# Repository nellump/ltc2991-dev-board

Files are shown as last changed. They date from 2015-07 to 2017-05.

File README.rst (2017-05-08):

LTC2991 Development Board
=========================

A simple printed circuit board that makes it easy to plug the
surface-mount (MSOP-16) `LTC2991`_ into a common breadboard.

.. _LTC2991: http://www.linear.com/product/LTC2991

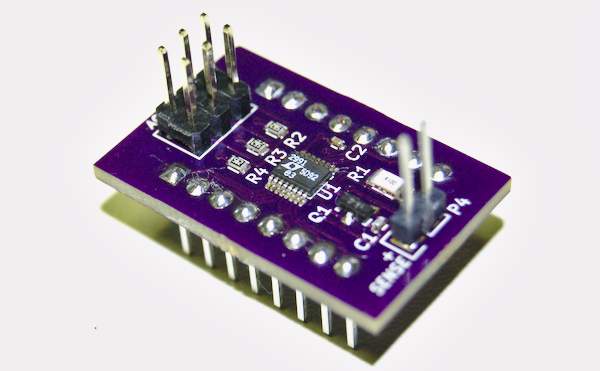
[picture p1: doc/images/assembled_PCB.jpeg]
Photo of LTC2991 breakout board.


   A fully-assembled LTC2991 breakout board, ready for service.

Features
--------

* A pair of pin headers for each of the LTC2991's address lines.
  Jumpering the pins on any given address line connects that line to
  ground.
* Pads suitable for a current-sensing shunt resistor (1206 SMD),
  connected across the V1 and V2 terminals of the LTC2991, and pads
  for a 1x2 pin header to connect said shunt to the outside world.
* Pads suitable for a temperature-sensing, diode-connected NPN BJT
  (SOT-23 SMD), connected across the V3 and V4 terminals of the
  LTC2991, and a filter capactitor for said transistor.

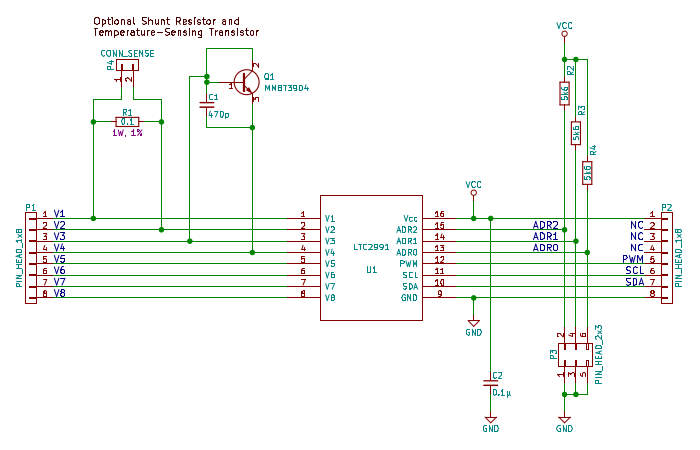
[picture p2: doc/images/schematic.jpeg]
Carrier board schematic.


   Carrier board schematic.  A PDF copy is in the build/ subdirectory.

Caveats
-------

There seems to be no such thing as a breadboard standard.  This PCB
was designed to work with an `R.S.R.-branded breadboard`_.  It
features a 0.100" pin pitch, and an approx. 0.300" gap down the middle
of the board.

.. _R.S.R.-branded breadboard: http://rsrelectronics.com/breadboards.html

Changelog
---------

Rev. A
~~~~~~
Initial design.

Rev. B
~~~~~~
* Added two-pin header for measurement of external current source
  via on-board shunt resistor (both optional).
* Added filter capacitor for IC power.
* Added filter capacitor for temperature-sensing transistor (both
  optional).
* Placed noise-shielding traces around temperature-sensing
  transistor.

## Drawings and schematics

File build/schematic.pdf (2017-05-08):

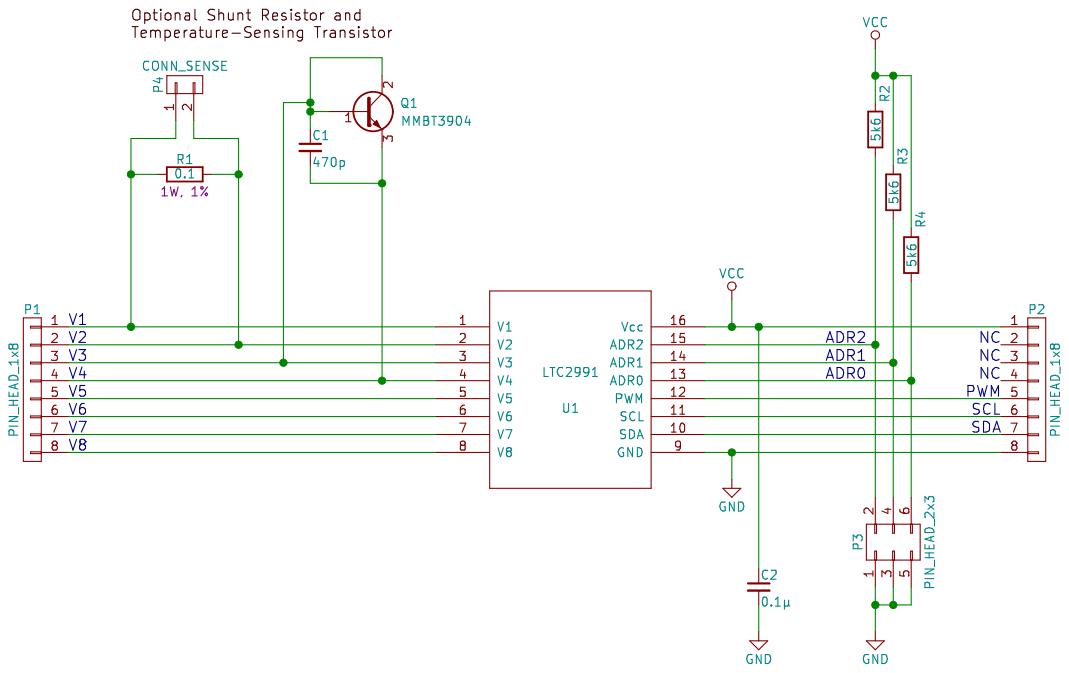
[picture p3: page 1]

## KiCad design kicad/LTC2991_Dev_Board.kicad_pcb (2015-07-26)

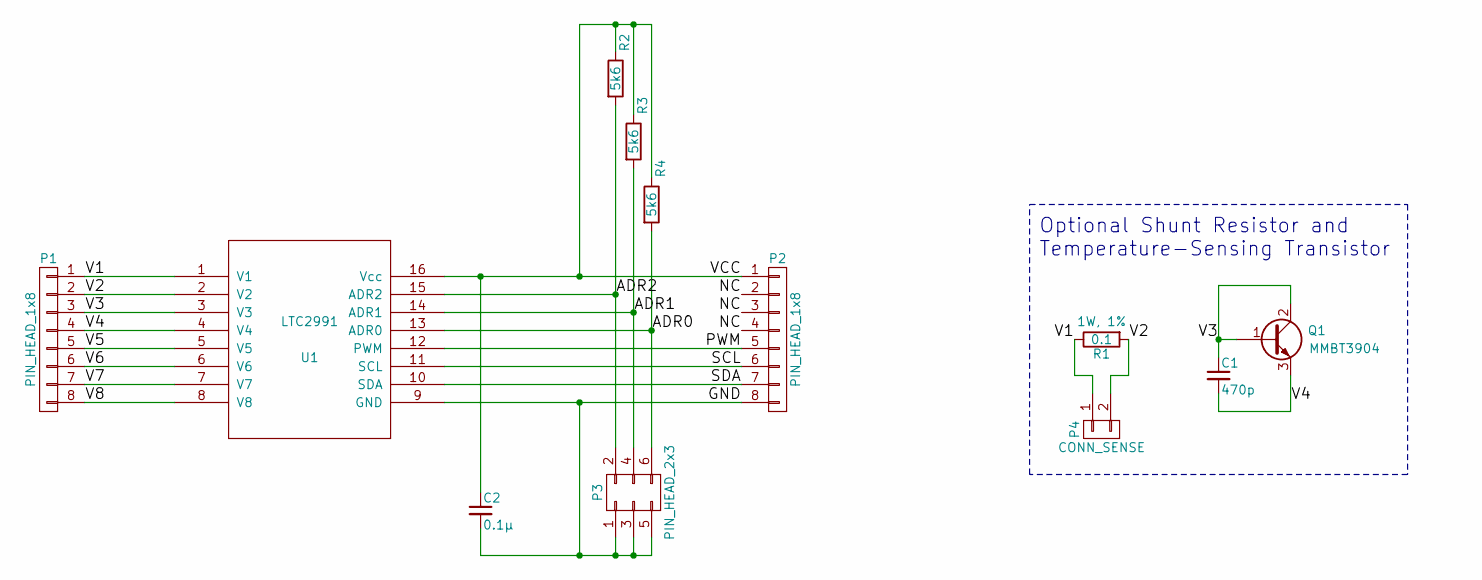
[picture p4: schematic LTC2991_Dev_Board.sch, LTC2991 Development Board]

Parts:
C1: 470p; C_0402
C2: 0.1μ; C_0402
P1, P2: PIN_HEAD_1x8; Pin_Header_Straight_1x08
P3: PIN_HEAD_2x3; Pin_Header_Straight_2x03
P4: CONN_SENSE; Pin_Header_Straight_1x02
Q1: MMBT3904; SOT-23
R1: 0.1; R_1206
R2, R3, R4: 5k6; R_0603
U1: LTC2991; MSOP-16

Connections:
/ADR0: P3.6, R4.2, U1.13 (ADR0)
/ADR1: P3.4, R3.2, U1.14 (ADR1)
/ADR2: P3.2, R2.2, U1.15 (ADR2)
/GND: C2.2, P2.8, P3.1, P3.3, P3.5, U1.9 (GND)
/NC: P2.2, P2.3, P2.4
/PWM: P2.5, U1.12 (PWM)
/SCL: P2.6, U1.11 (SCL)
/SDA: P2.7, U1.10 (SDA)
/V1: P1.1, P4.1, R1.1, U1.1 (V1)
/V2: P1.2, P4.2, R1.2, U1.2 (V2)
/V3: C1.1, P1.3, Q1.1 (B), Q1.2 (C), U1.3 (V3)
/V4: C1.2, P1.4, Q1.3 (E), U1.4 (V4)
/V5: P1.5, U1.5 (V5)
/V6: P1.6, U1.6 (V6)
/V7: P1.7, U1.7 (V7)
/V8: P1.8, U1.8 (V8)
/VCC: C2.1, P2.1, R2.1, R3.1, R4.1, U1.16 (Vcc)

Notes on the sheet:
Optional Shunt Resistor and Temperature-Sensing Transistor

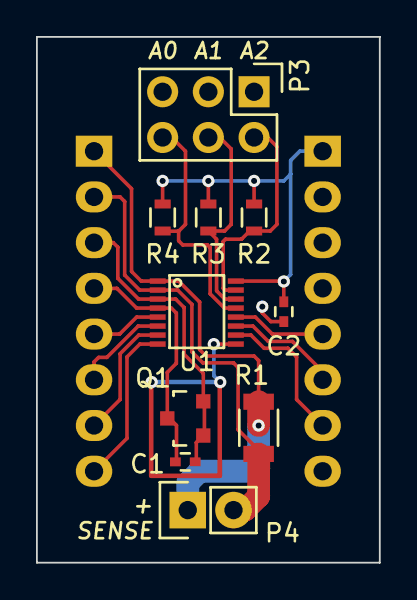
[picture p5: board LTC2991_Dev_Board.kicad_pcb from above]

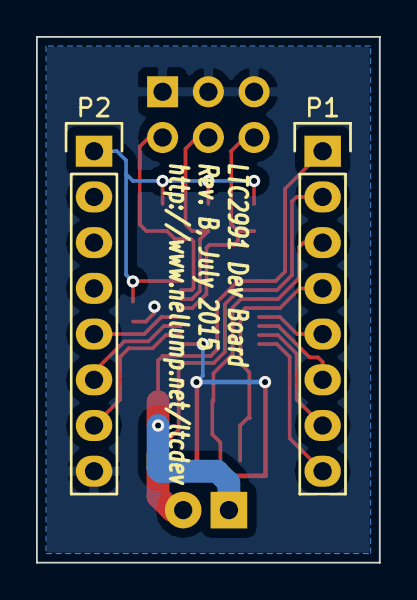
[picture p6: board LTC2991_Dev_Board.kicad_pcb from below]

Board: 2 copper layers, 19.1 x 29.2 mm, 12 parts (2 on the bottom side), 17 nets.

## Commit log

2015-07-12 First draft of dev board schematic.
    [LTC2991_Dev_Board.sch]
2015-07-13 Beginning stages of PCB layout. Likely to need a few modifications to meet board size requirements.
    [LTC2991_Dev_Board.kicad_pcb, LTC2991_Dev_Board.sch]
2015-07-13 More PCB layout work, schematic tweaks. Closer to a finaly layout.
    [LTC2991_Dev_Board.kicad_pcb, LTC2991_Dev_Board.sch]
2015-07-15 Final schematic and PCB layout for Rev. A. Significantly simplified the schematic in order to make the board as compact as possible.
    [LTC2991_Dev_Board-B_Cu.gbr, LTC2991_Dev_Board-B_Mask.gbr, LTC2991_Dev_Board-B_SilkS.gbr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]
2015-07-15 Minor adjustment to PCB silkscreen. Added labels to pins in address jumper. Moved board name to front side.
    [LTC2991_Dev_Board.kicad_pcb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]
2015-07-15 Moved Gerber files out of ./kicad/ and into the top level. Generated/compiled files should have their own home.
    [LTC2991_Dev_Board-B_Cu.gbr, LTC2991_Dev_Board-B_Mask.gbr, LTC2991_Dev_Board-B_SilkS.gbr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]
2015-07-15 Added README, PDF of schematic.
2015-07-16 Created Gerber for front side solder paste. Added it to the gerbv project file.
    [LTC2991_Dev_Board-F_Paste.gbr]
2015-07-18 Minor adjustments to text on PCB's back silkscreen.
    [LTC2991_Dev_Board.kicad_pcb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]
2015-07-26 Modified schematic and PCB layout. 1. Added two-pin header for measurement of external current source via on-board shunt resistor (both optional). 2. Added filter capacitor for IC power. 3. Added fil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
    [LTC2991_Dev_Board-B_Cu.gbr, LTC2991_Dev_Board-B_Mask.gbr, LTC2991_Dev_Board-B_SilkS.gbr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]
2015-07-26 Rearranged schematic. In the hopes of making it a bit more readable. Updated PCB layout with new netlist (no significant changes).
    [LTC2991_Dev_Board.kicad_pcb, LTC2991_Dev_Board.sch]
2015-07-26 Updated README, title blocks in KiCad drawings.
    [LTC2991_Dev_Board.kicad_pcb, LTC2991_Dev_Board.sch]
2015-07-26 Minor adjustment to back silk screen text.
    [LTC2991_Dev_Board.kicad_pcb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]
2015-07-26 Grounded Faraday traces surrounding temp-sensing transistor.
    [LTC2991_Dev_Board.kicad_pcb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]
2015-09-30 Deleted unused symbols and footprints.
2015-12-04 Removed unused symbol library from schematic.
2016-12-10 Rearranged repo to match preferred hardware project layout.
    [LTC2991_Dev_Board-B_Cu.gbr, LTC2991_Dev_Board-B_Mask.gbr, LTC2991_Dev_Board-B_SilkS.gbr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]
2017-05-08 Cleaned up schematic for sake of readability. No functional changes.
    [LTC2991_Dev_Board.sch]
2017-05-08 Updated README to reflect recent schematic changes.
2017-05-08 Removed link to schematic PDF from README.
    It did not work as expected with cgit.
